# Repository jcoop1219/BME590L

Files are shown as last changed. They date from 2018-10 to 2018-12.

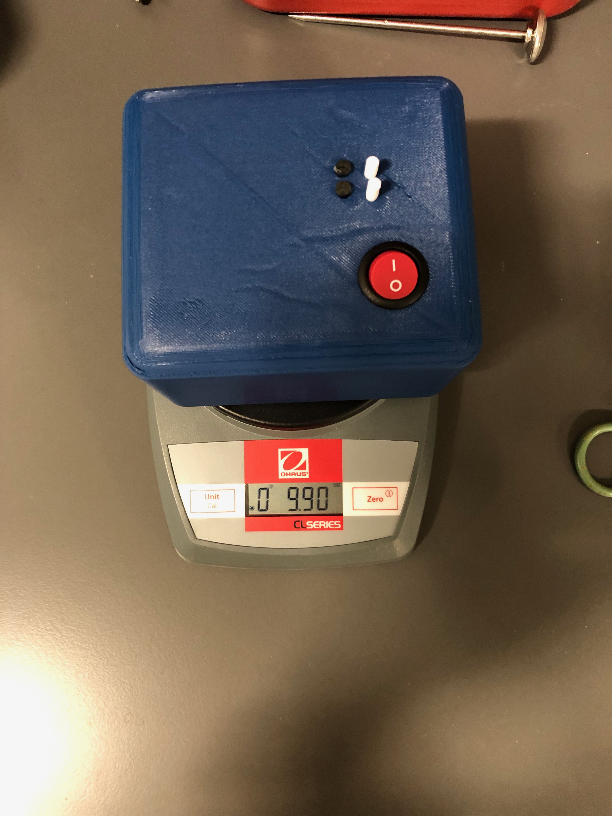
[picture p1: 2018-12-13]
Testing/Total weight.jpg

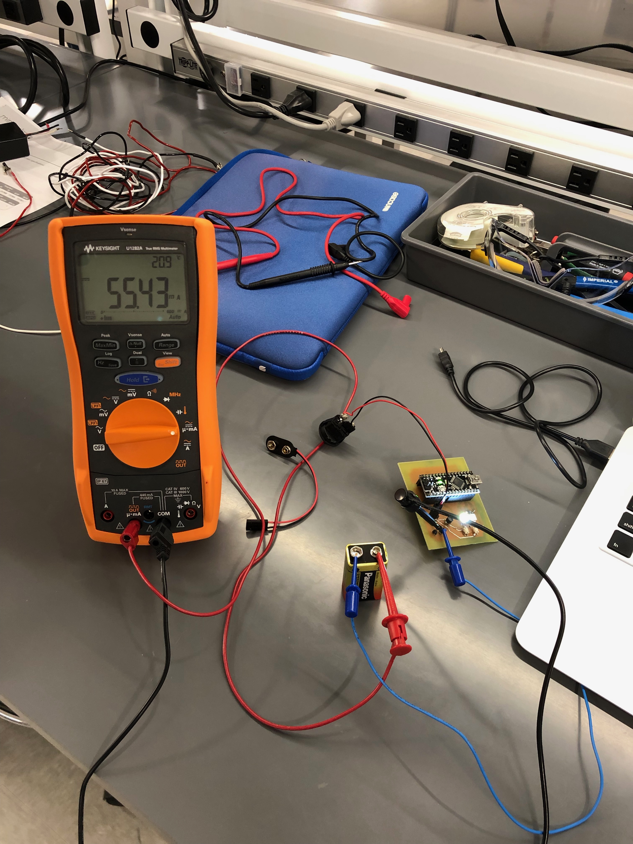
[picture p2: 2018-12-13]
Testing/Current draw.jpg

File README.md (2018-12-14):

# BME590L_Lightbulb - Design Skills Project (Variable Light Intensity)

See Final Working Video on [YouTube](https://youtu.be/NFrjT-VMIhY).

## Usage Guide
1. Turn on device using red I/O switch.
1. Push white button closest to I/O switch to cycle through light modes:
   + `Off`
   + `Brightest`
   + `Intermediate Brightness`
   + `Least Bright`
   + `Flashing @ 2 Hz`
1. Push and hold white button furthest from I/O switch to show the remaining voltage left in the battery on the adjacent LED:
   + `GREEN` = battery high (>8V)
   + `BLUE` = battery medium (7-8V)
   + `RED` = battery low (<7V)

## Battery Replacement
1. Spin flaps on bottom away from center of device.
1. Pull top of case off of bottom of case and disconnect toggle switch Molex connection from board.
1. Remove battery wire Molex connection from board.
1. Remove battery from battery slot.
1. Detach wired cap from battery.
1. Attach wired cap to new battery.
1. Add new battery to battery slot.
1. Re-attach battery wire Molex connection to board.
1. Reconnect toggle switch Molex connection to board.
1. Replace case top over case bottom (note: may need to use tweezers or small object to guide push buttons through case top).
1. Spin flaps on bottom towards center of device.

## Documentation
1. [Bill of Materials](https://github.com/jcoop1219/BME590L_Lightbulb/blob/master/Documentation/Bill%20of%20Materials.xlsx)
1. [Final Device Photos](https://github.com/jcoop1219/BME590L_Lightbulb/tree/master/Documentation/Final%20Device%20Photos)
1. [Testing Videos](https://github.com/jcoop1219/BME590L_Lightbulb/tree/master/Testing/Videos)

## Other Misc Notes:
+ Total weight = 9.9 oz
+ Current draw while on = 55 mA (lasts 7.2 hours on standard 9V battery)
+ Current draw while off = 0 mA (full off ensured by toggle I/O switch)

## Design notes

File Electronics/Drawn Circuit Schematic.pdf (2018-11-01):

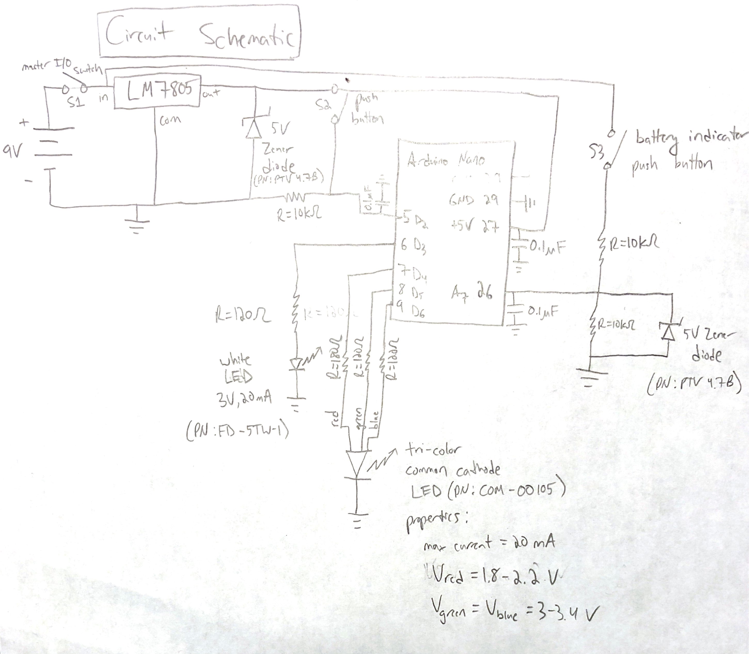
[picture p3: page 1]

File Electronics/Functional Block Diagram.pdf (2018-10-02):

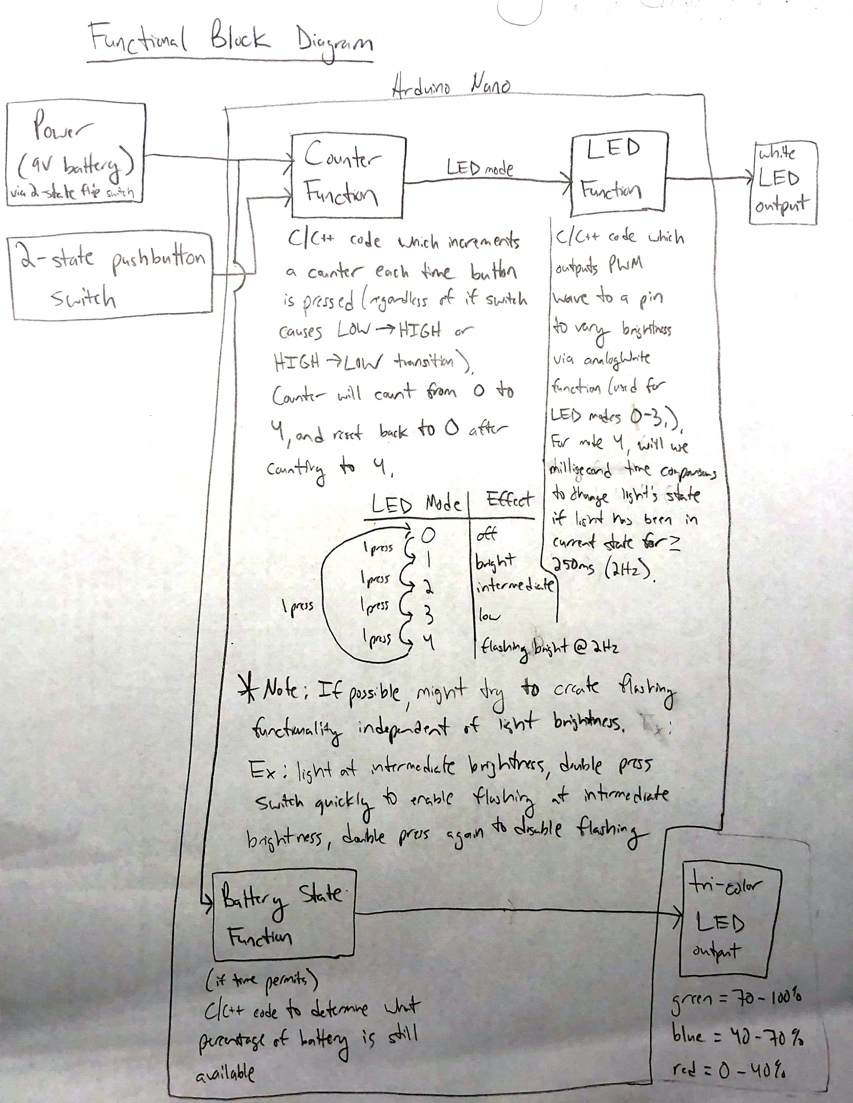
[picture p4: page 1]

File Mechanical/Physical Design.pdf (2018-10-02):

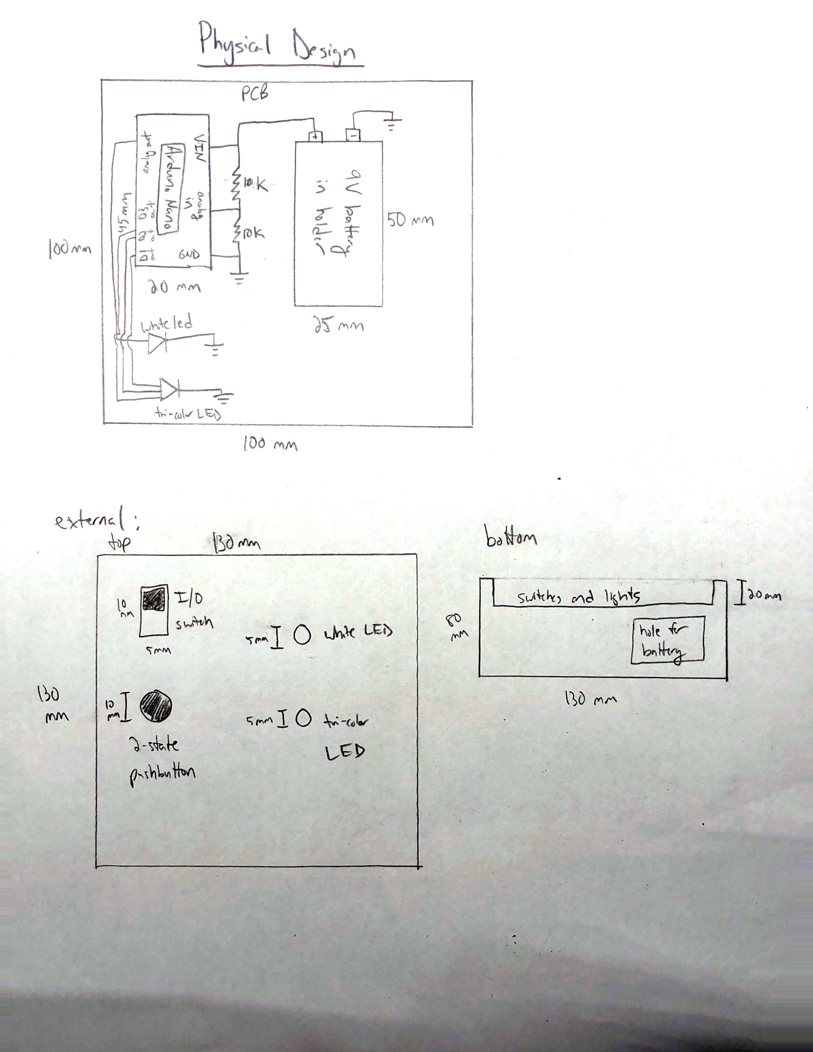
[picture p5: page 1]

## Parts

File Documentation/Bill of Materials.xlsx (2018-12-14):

Item | Cost/Unit | Units | Cost | Source
3D printed items* | $14.24 | 1 | $14.24 | https://www.makeshaper.com/product/blue-pla-2-85-mm-filament/
PCB | $1.00 | 1 | $1.00 | https://www.ebay.com/itm/DIY-Single-PCB-Circuit-Kit-Board-Glass-Fiber-One-Side-Copper-Clad-70x100x1-5mm-/142234873243
Arduino Nano | $22.00 | 1 | $22.00 | https://store.arduino.cc/usa/arduino-nano
9V Battery | $2.38 | 1 | $2.38 | https://www.mouser.com/ProductDetail/Panasonic-Battery/6LF22XWA-B12
Light Pipe LPCR012CTP | $0.53 | 2 | $1.06 | https://www.amazon.com/gp/product/B01N5DIWD6/ref=oh_aui_detailpage_o01_s00?ie=UTF8&psc=1
Push Button SKRPABE010 | $0.36 | 2 | $0.72 | https://www.mouser.com/ProductDetail/ALPS/SKRPABE010?qs=m0BA540hBPe1GpcSf%2FZ5Yw==
SMT Cool White 5050 LED | $0.49 | 1 | $0.49 | https://www.adafruit.com/product/682
SMT RGB 5050 LED | $0.49 | 1 | $0.49 | https://www.adafruit.com/product/619
Toggle Switch RRA22H3FBRNN | $1.28 | 1 | $1.28 | https://www.digikey.com/products/en?mpart=RRA22H3FBRNN&v=85
Voltage Regulator LM7805 TO92 | $1.50 | 1 | $1.50 | https://www.adafruit.com/product/2236
Zener Diode 1n5221 | $0.19 | 1 | $0.19 | https://www.mouser.com/ProductDetail/Vishay-Semiconductors/1N5221B-TAP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
SMT Resistor | $0.11 | 7 | $0.77 | https://www.mouser.com/ProductDetail/Yageo/RC0805JR-070RL?qs=3ldFlDWnkKyEhdaPjQHEFA==
SMT Capacitor | $0.13 | 3 | $0.39 | https://www.digikey.com/product-detail/en/murata-electronics-north-america/GRM2165C1H101JA01D/490-1615-1-ND/587513
Uncountable hours of Matt Brown's time | priceless
TOTAL |  |  | $46.52
*3D printed items calculations:
Piece | Volume (cm^3) | Density of PLA (g/cm^3)** | Cost of PLA ($USD/kg)*** | Total Cost ($USD)
Case Top | 338.68
Case Bottom | 197.16
Plungers (2) | 4.48
Flaps (2) | 0.70
Plunger track | 1.40
TOTAL | 542.42 | 1.25 | $21.00 | $14.24
**https://www.fabbaloo.com/blog/2015/9/27/is-it-filament-weight-or-length
***https://www.makeshaper.com/product/blue-pla-2-85-mm-filament/

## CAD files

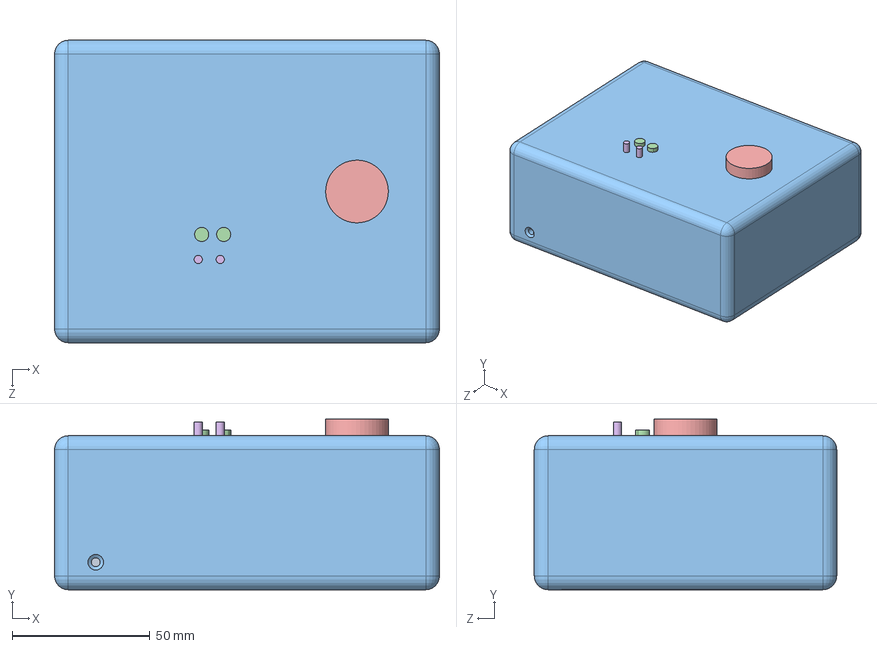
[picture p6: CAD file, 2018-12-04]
Mechanical/Original CAD Design/Case Assembly.SLDASM
140.0 x 62.0 x 110.0 mm
Case Bottom
PCB
Case Top
LCV 116 CTP x 2
Toggle Switch
Push Button Plunger x 2

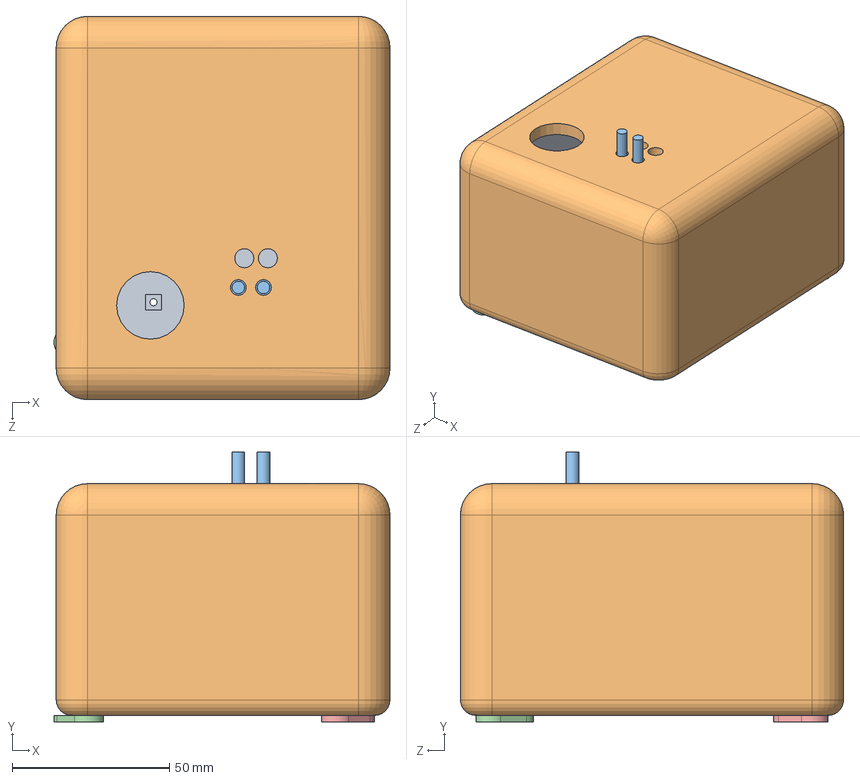
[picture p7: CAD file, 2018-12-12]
Mechanical/New CAD Design/NEW Case Assembly.SLDASM
107.0 x 85.8 x 122.0 mm
NEW Case Bottom
NEW Case Top
NEW Push Button Plunger x 2
Flap Bottom
Flap Bottom 2

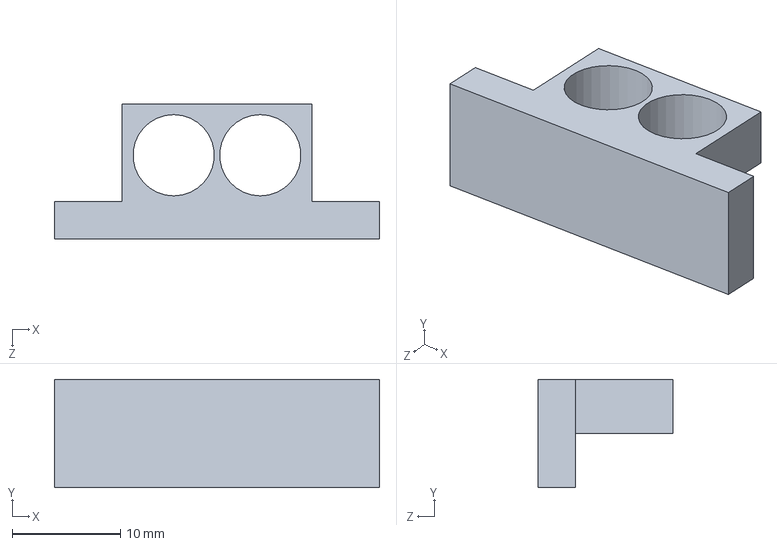
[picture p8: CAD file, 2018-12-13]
Mechanical/New CAD Design/Plunger Track.SLDPRT
30.0 x 10.0 x 12.5 mm

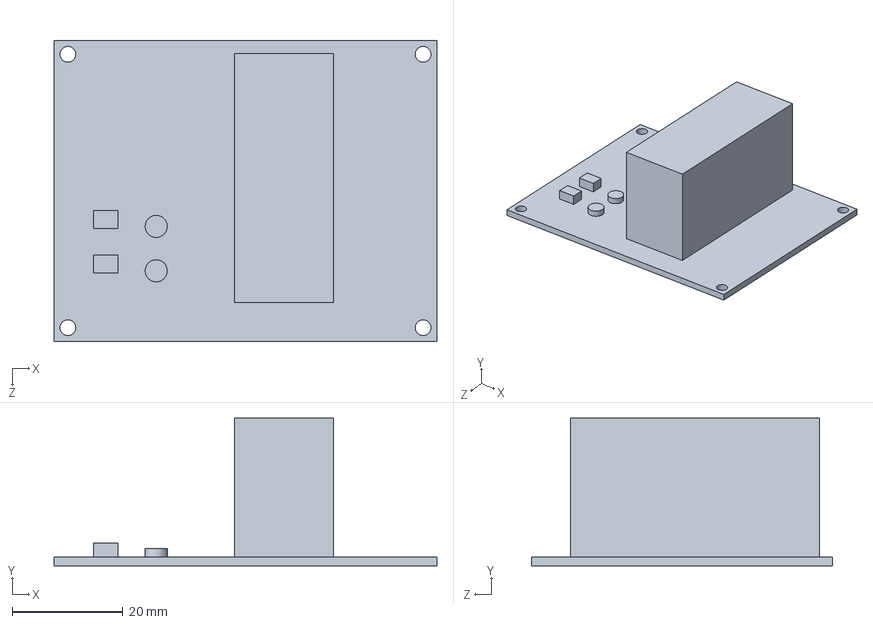
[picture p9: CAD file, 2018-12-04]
Mechanical/Original CAD Design/PCB.SLDPRT
69.0 x 26.6 x 54.3 mm

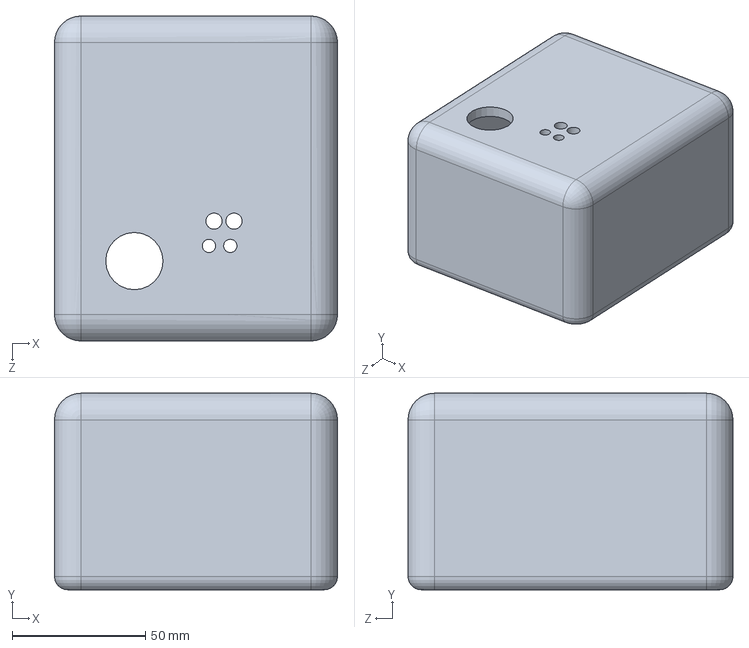
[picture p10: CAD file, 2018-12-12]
Mechanical/New CAD Design/NEW Case Top.SLDPRT
106.3 x 73.8 x 122.0 mm

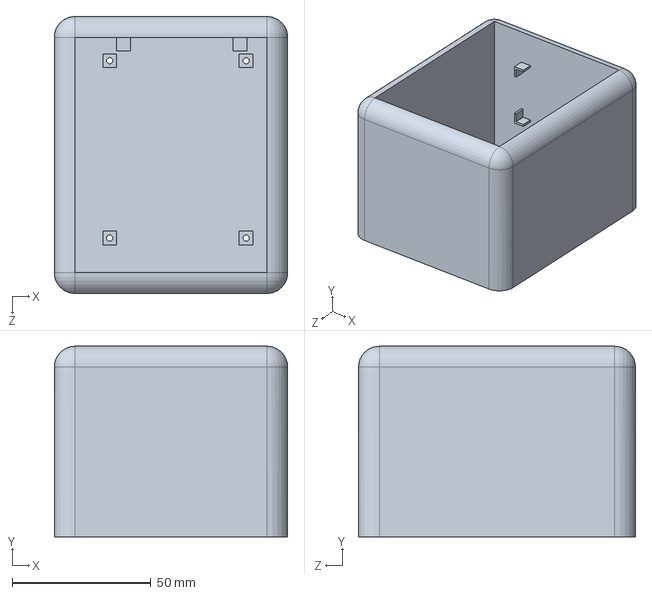
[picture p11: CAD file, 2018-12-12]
Mechanical/New CAD Design/NEW Case Bottom.SLDPRT
84.3 x 68.8 x 100.0 mm

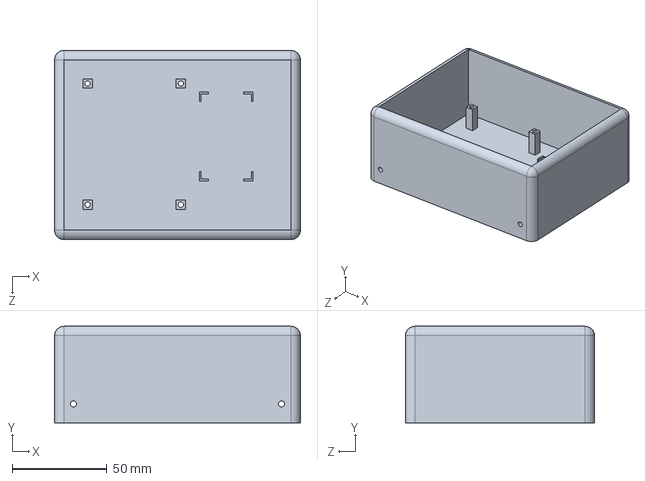
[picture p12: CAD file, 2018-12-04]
Mechanical/Original CAD Design/Case Bottom.SLDPRT
130.0 x 51.0 x 100.0 mm

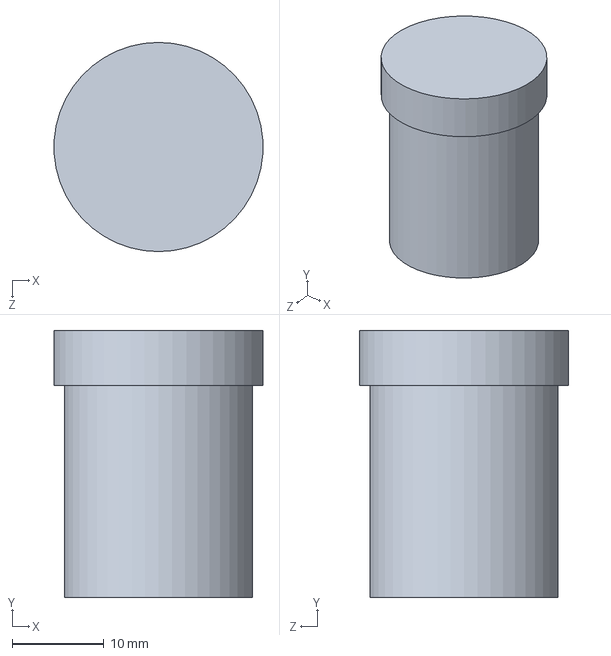
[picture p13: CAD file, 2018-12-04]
Mechanical/Original CAD Design/Toggle Switch.SLDPRT
22.7 x 29.1 x 22.8 mm

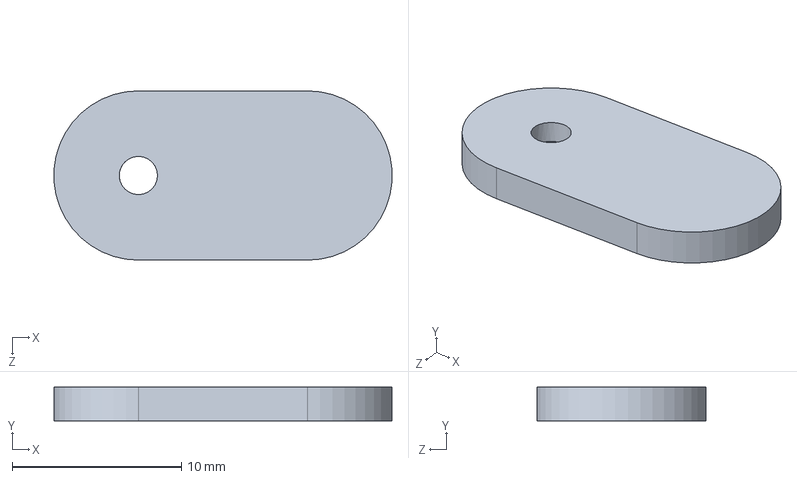
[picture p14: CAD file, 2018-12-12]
Mechanical/New CAD Design/Flap Bottom.SLDPRT
20.0 x 2.00 x 10.0 mm

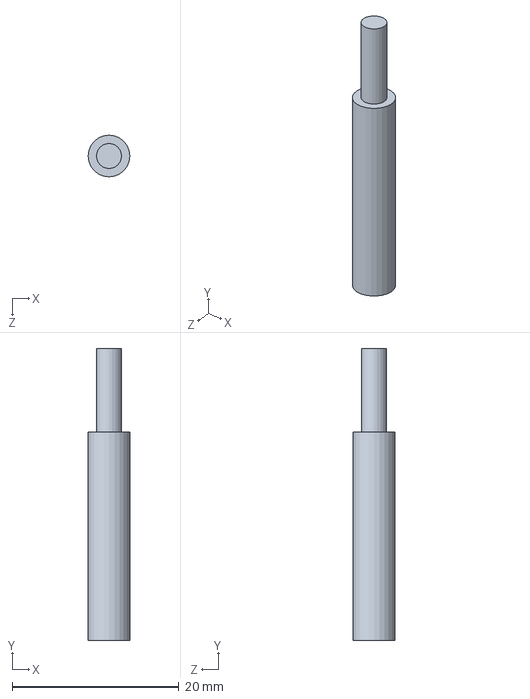
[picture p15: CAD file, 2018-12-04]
Mechanical/Original CAD Design/Push Button Plunger.SLDPRT
5.00 x 35.0 x 5.00 mm

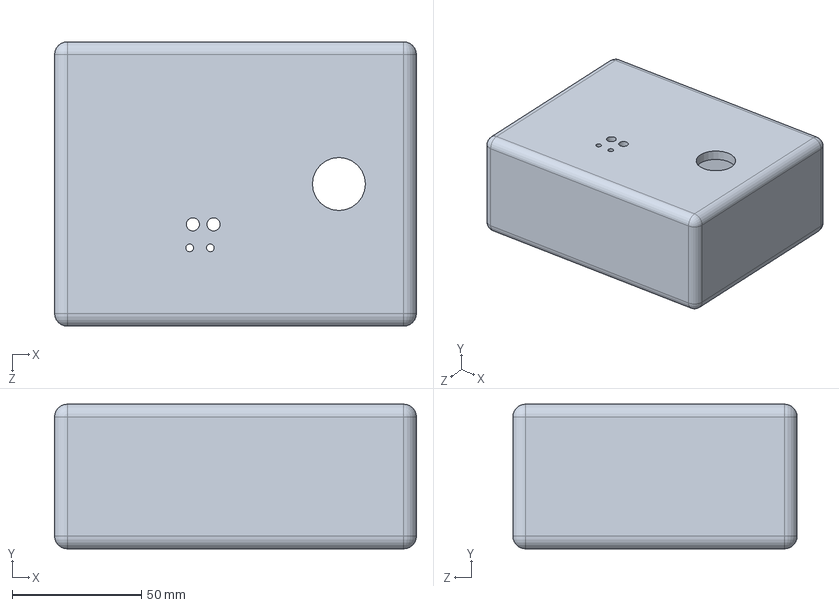
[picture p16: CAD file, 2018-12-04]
Mechanical/Original CAD Design/Case Top.SLDPRT
140.0 x 56.0 x 110.0 mm

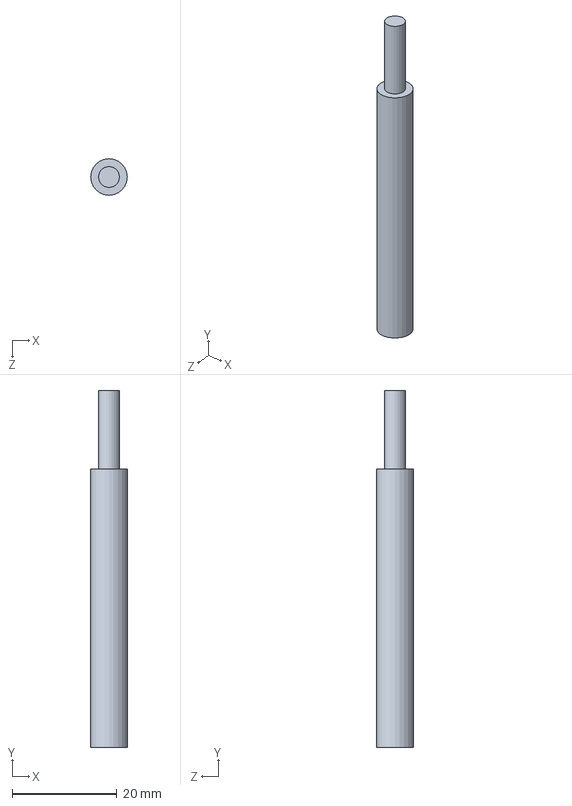
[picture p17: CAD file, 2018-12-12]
Mechanical/New CAD Design/NEW Push Button Plunger.SLDPRT
7.00 x 68.3 x 7.00 mm

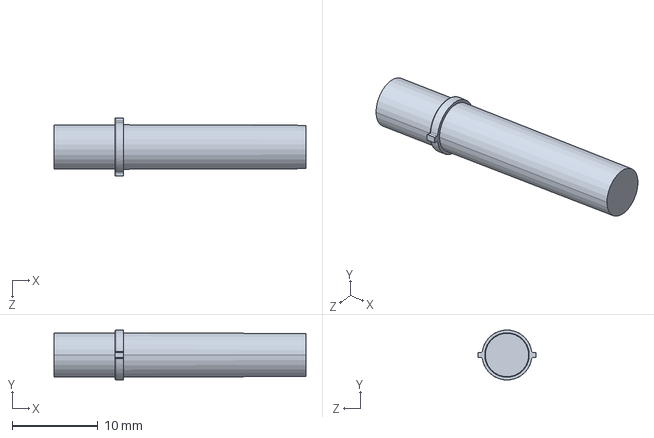
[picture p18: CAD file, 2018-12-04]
Mechanical/Original CAD Design/LCV 116 CTP.SLDPRT
29.5 x 5.84 x 6.76 mm

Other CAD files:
Mechanical/New CAD Design/Flap Bottom 2.SLDPRT
Mechanical/New CAD Design/NEW Push Button Plunger 2.STL
Mechanical/New CAD Design/Flap Bottom 2.STL
Mechanical/New CAD Design/Flap Bottom.STL
Mechanical/New CAD Design/NEW Case Bottom.STL
Mechanical/New CAD Design/NEW Case Top.STL
Mechanical/New CAD Design/NEW Push Button Plunger.STL
Mechanical/New CAD Design/Plunger Track.STL
Mechanical/Original CAD Design/Case Bottom.STL
Mechanical/Original CAD Design/Case Top.STL
Mechanical/Original CAD Design/Push Button Plunger.STL

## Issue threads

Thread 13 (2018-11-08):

Milestone 04 ready for review

jcoop1219, 2018-11-08:
Will also assign to Matt and Brinnae after they accept my invite as collaborators

mlp6, 2018-11-08:
@jcoop1219 you don't seem to like sleep...

mlp6, 2018-11-08:
Let's also add @ericsrichardson

jcoop1219, 2018-11-08:
See minor updates & notes in release v0.2.1

jcoop1219, 2018-11-12:
See newest updates in release v0.2.3

sphaerobolus, 2018-11-12:
I don't think you need ground planes top and bottom. Pick one.

I understand D1, though my opinion is that you don't need it. D1's existence implies you might not trust the voltage regulator. If you don't trust the regulator, get a better one.

I'm not sure I understand D4, nor the use of an analog pin as a switch input.

jcoop1219, 2018-11-12:
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

1. Is there any drawback to having 2 ground planes? I figured having a second ground plane could only help with insulating the circuit from external noise.
2. D1 is really there for the purposes of testing the circuit (like, when building out on breadboard). Using it to make sure I'm not discharging any static electricity >5V from my clothing to the Arduino. I'll remove D1 from the PCB.
3. I'm using this analog input as a battery voltage tester (to see how much juice is left in the battery). Ideally what's going into this input should never be above 4.5V (9V battery divided by 2 via voltage divider). D4 ensures this voltage won't go above 5.1V and I won't fry the Arduino.

jcoop1219, 2018-11-12:
@sphaerobolus please see my comment above in response to your questions

sphaerobolus, 2018-11-12:
In your case I think the added plane will merely be redundant. In some cases it can be problematic. It's not doing you much good. The positive effects do not add linearly.

Ah, now I understand the analog input. In that case, I'm on board. Carry on.

jcoop1219, 2018-11-12:
Thanks! I'll go ahead and remove the bottom layer ground plane, as well as remove D1 per the discussion above.

Closed 2018-11-12.

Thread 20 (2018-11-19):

Add screw holes to box design

jcoop1219, 2018-11-19:

jcoop1219, 2018-11-27:
- Most common screw in lab: 4-40
- Wood screws fine to use as long as not often screwing/unscrewing; tap into material
- Machine screw need threaded entity to go into or a nut

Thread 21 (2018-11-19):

Milestone 05 ready for review

jcoop1219, 2018-11-19:
See latest release notes for [v0.3.0](https://github.com/jcoop1219/BME590L_Lightbulb/releases/tag/v0.3.0)

mlp6, 2018-11-26:
@jcoop1219 how do your top and bottom secure to one another?  There also seem to be a lack of internal mounting points for the board(s), battery, etc.

mlp6, 2018-11-26:
Noticed you still have some open Issues that will address some of these things.

jcoop1219, 2018-12-03:
These issues (attachment of top to bottom, battery attachment, PCB) all addressed newest release [v0.3.1](https://github.com/jcoop1219/BME590L_Lightbulb/releases/tag/v0.3.1)

mlp6, 2018-12-03:
Impressive!

jcoop1219, 2018-12-03:
Thanks! Do you think I'm good to proceed with printing this?

mlp6, 2018-12-04:
I think so... but there is no substitute for evaluating it in tangible form (for me).

Closed 2018-12-08.

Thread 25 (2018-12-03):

Look into springs for button plungers

jcoop1219, 2018-12-03:

jcoop1219, 2018-12-11:
Not going to pursue this. Will just give very small (2-3 mm) clearance where button might wiggle a little up and down but should be held in box by mechanical design.

Closed 2018-12-11.

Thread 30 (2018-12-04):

Battery testing circuit working erratically

jcoop1219, 2018-12-04:
When pushing button to test circuit, correct LED lights up (shows red, green, or blue based on the voltage left in the battery). After letting button go, red LED lights up briefly. It seems that the analog in pin is seeing some stray voltage even after that part of the circuit is switched off. I would guess that there's some sort of stray capacitance which is discharging and causing this behavior.

I removed the nearby bypass capacitor, but that didn't seem to do the trick.

Is it possible that one of the other capacitors (in completely different parts of circuit) are causing this stray capacitance? Or could it be the solder pattern on the board?

Will try to solve this with a software-side solution...

jcoop1219, 2018-12-08:
Fixed this by upping the lower threshold which considers the battery to be "dead"

Closed 2018-12-08.

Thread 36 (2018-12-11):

Mechanical redesign

jcoop1219, 2018-12-11:
1. Make all holes wider by 1-2mm
2. Give 1-2mm clearance all around
3. Shorten stumps for PCB placement to 7-10mm
4. Battery above PCB
5. Toggle switch moved directly above area where it plugs into on board
6. Light pipes either chained or chained and cut
7. Re-model plungers
8. More rounded edges

Closed 2018-12-12.

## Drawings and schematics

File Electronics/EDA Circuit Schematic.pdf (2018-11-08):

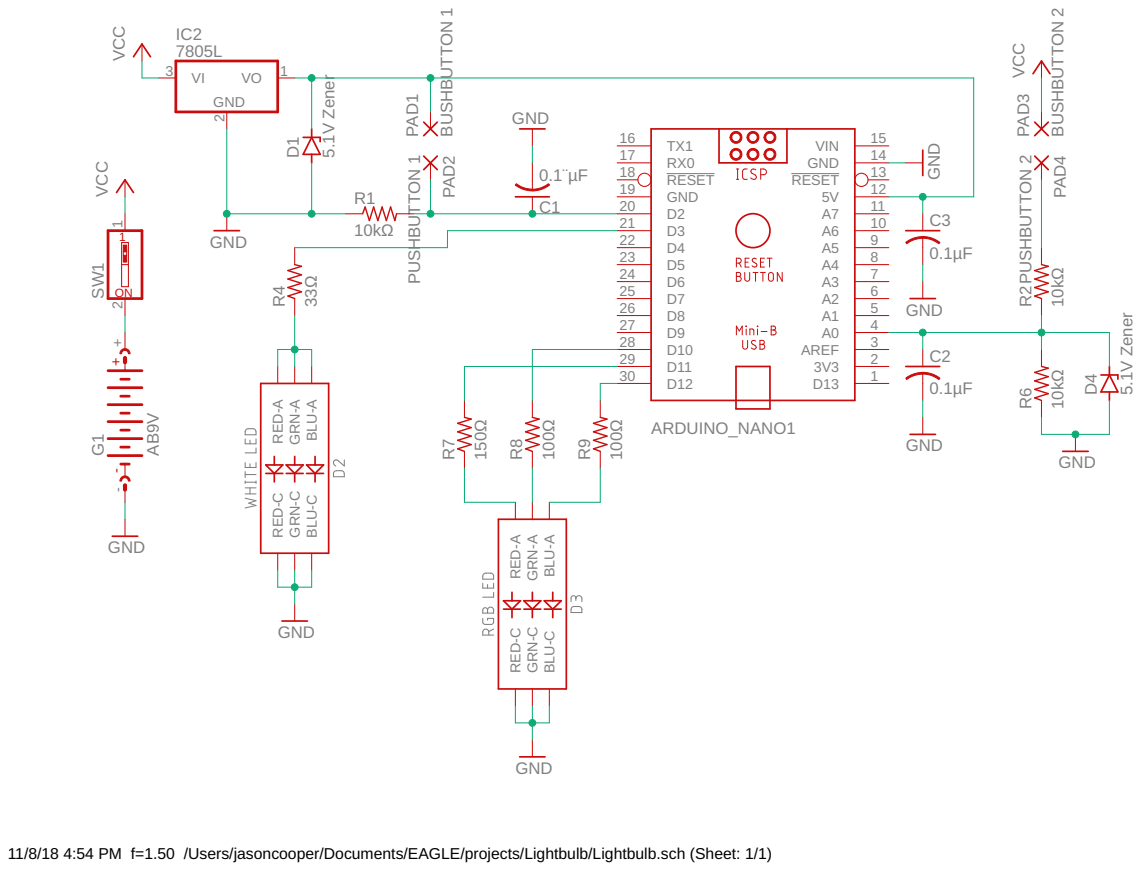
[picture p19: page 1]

GND

GND D2 D3 D4 D7 D8 | 5V | 14 VIN

11/8/18 4:54 PM f=1.50 /Users/jasoncooper/Documents/EAGLE/projects/Lightbulb/Lightbulb.sch (Sheet: 1/1)

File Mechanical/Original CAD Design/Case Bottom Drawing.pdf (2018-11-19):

108.000
106.000

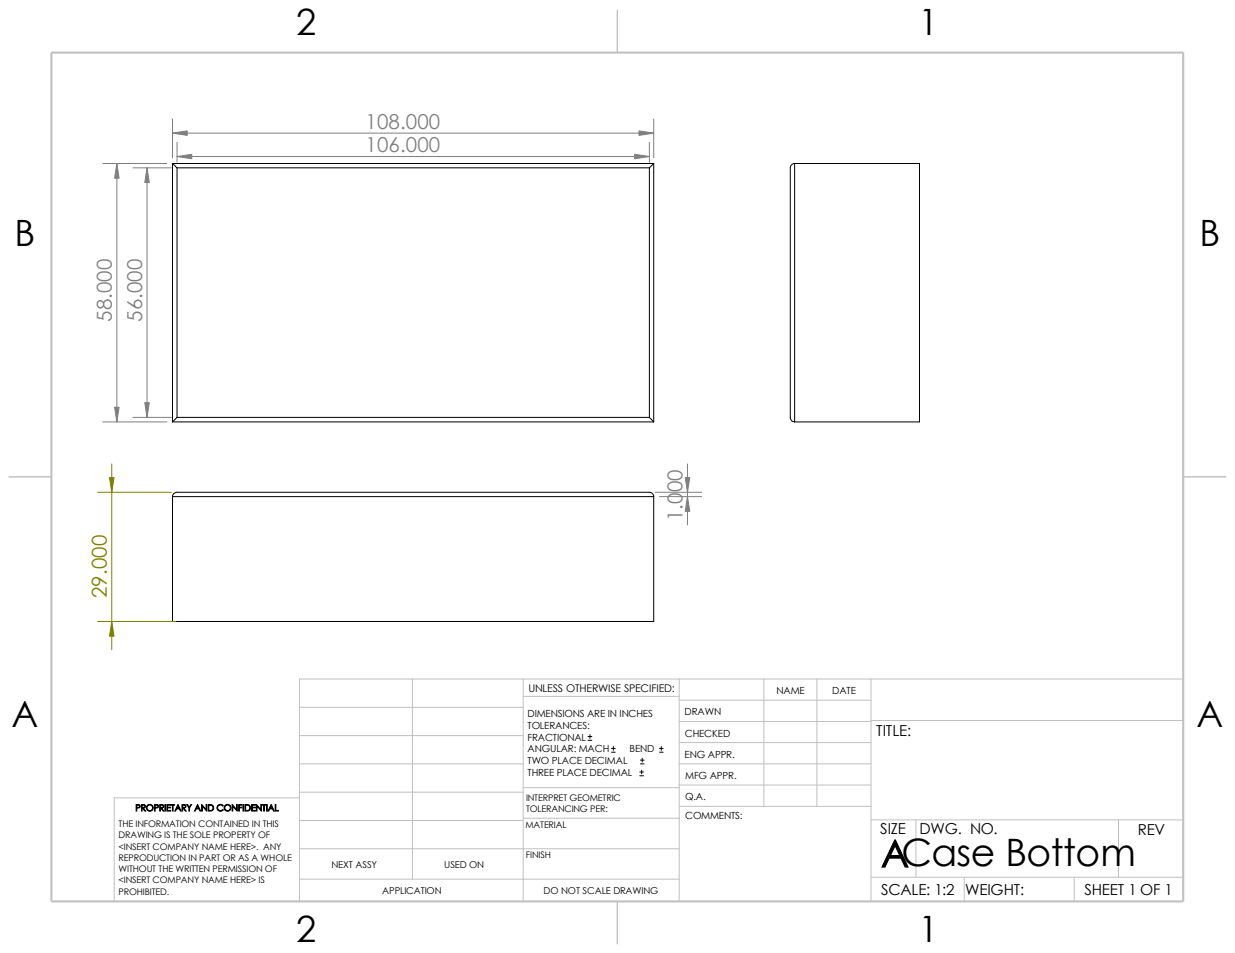
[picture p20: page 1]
COMMENTS:; INTERPRET GEOMETRIC; PROPRIETARY AND CONFIDENTIAL; TOLERANCING PER:

UNLESS OTHERWISE SPECIFIED: | | NAME | DATE

DIMENSIONS ARE IN INCHES TOLERANCES: FRACTIONAL ANGULAR: MACH BEND TWO PLACE DECIMAL THREE PLACE DECIMAL | DRAWN

CHECKED | | | TITLE:

ENG APPR.
MFG APPR.

THE INFORMATION CONTAINED IN THIS
DRAWING IS THE SOLE PROPERTY OF
<INSERT COMPANY NAME HERE>. ANY
REPRODUCTION IN PART OR AS A WHOLE
WITHOUT THE WRITTEN PERMISSION OF
<INSERT COMPANY NAME HERE> IS
PROHIBITED.

MATERIAL | | SIZE A Case Bottom | DWG. NO. | REV

NEXT ASSY | USED ON | FINISH

APPLICATION | DO NOT SCALE DRAWING | | SCALE: 1:2 | WEIGHT: | SHEET 1 OF 1

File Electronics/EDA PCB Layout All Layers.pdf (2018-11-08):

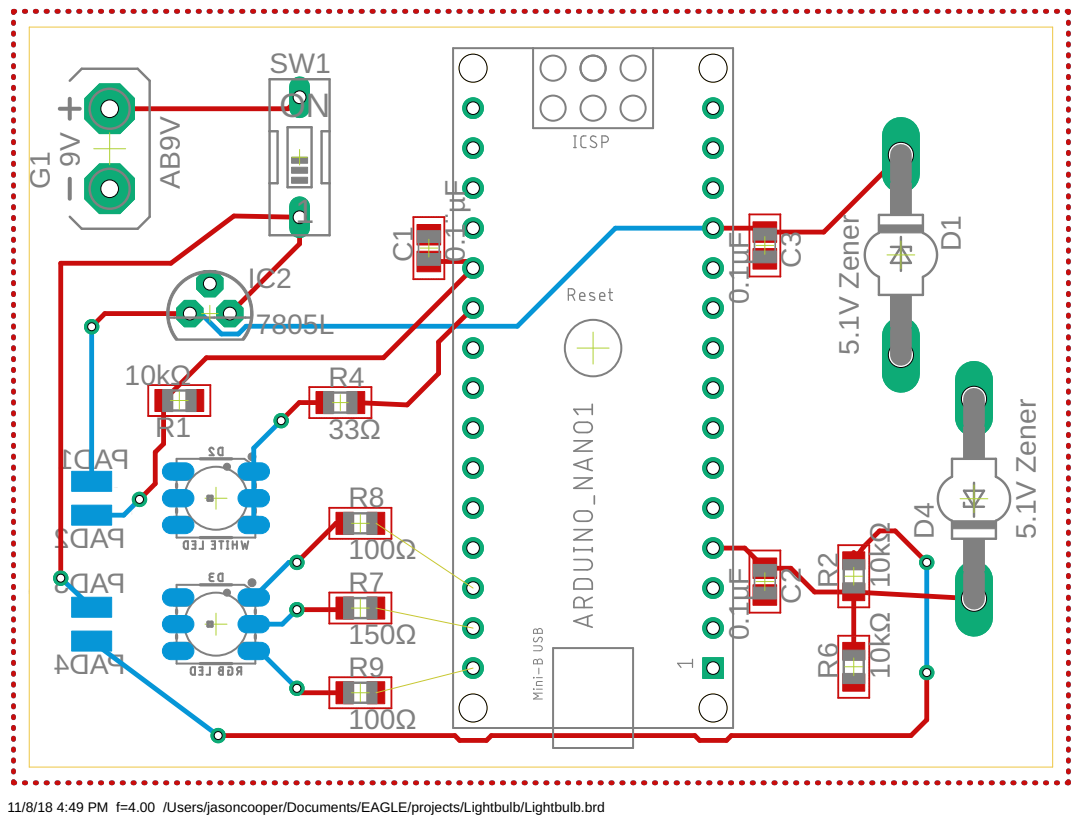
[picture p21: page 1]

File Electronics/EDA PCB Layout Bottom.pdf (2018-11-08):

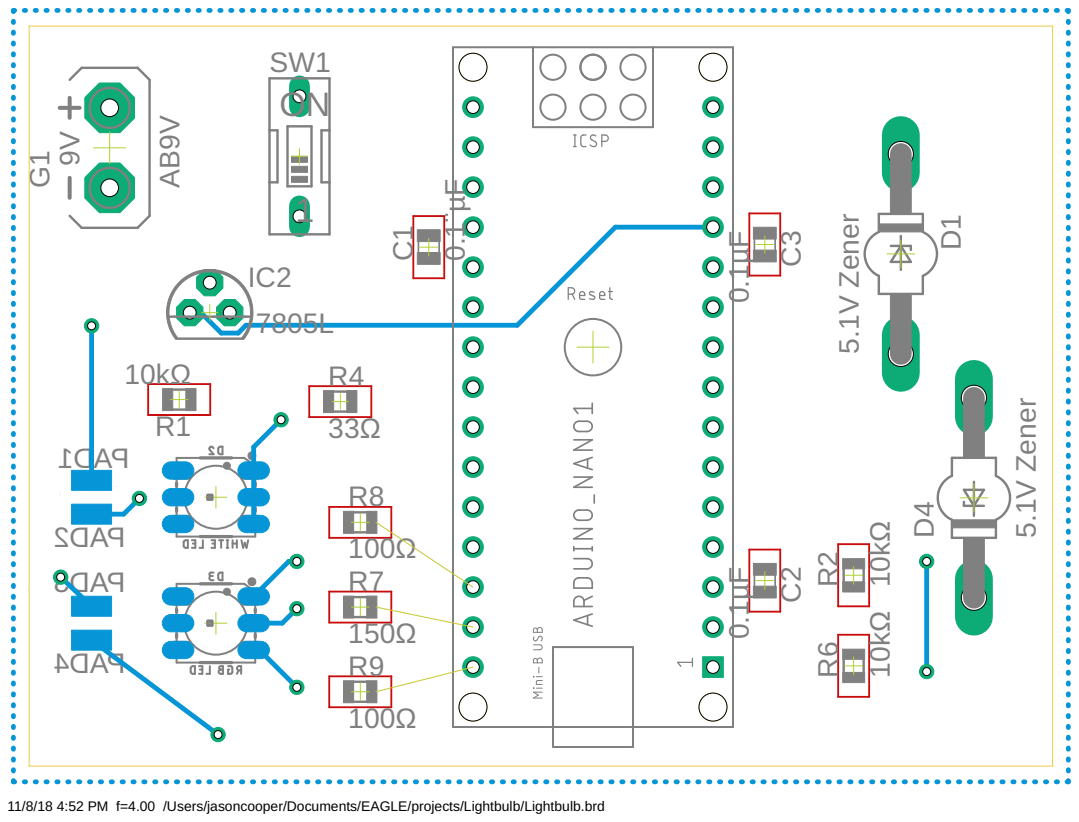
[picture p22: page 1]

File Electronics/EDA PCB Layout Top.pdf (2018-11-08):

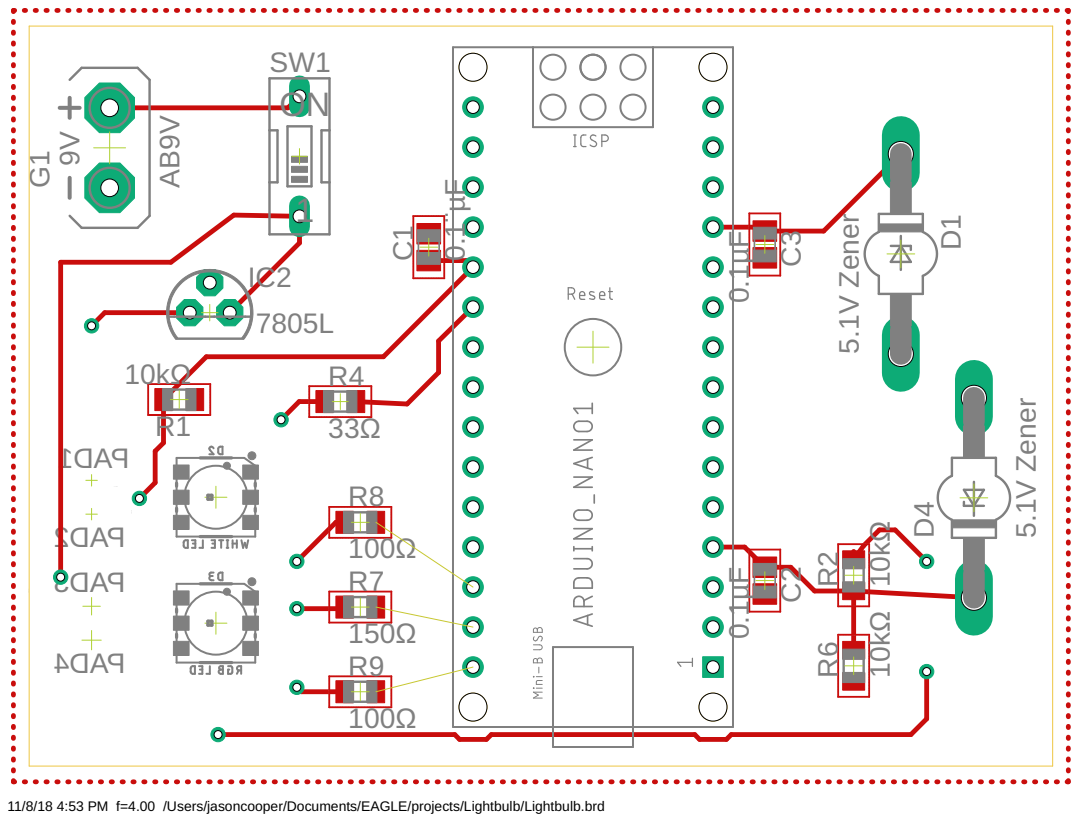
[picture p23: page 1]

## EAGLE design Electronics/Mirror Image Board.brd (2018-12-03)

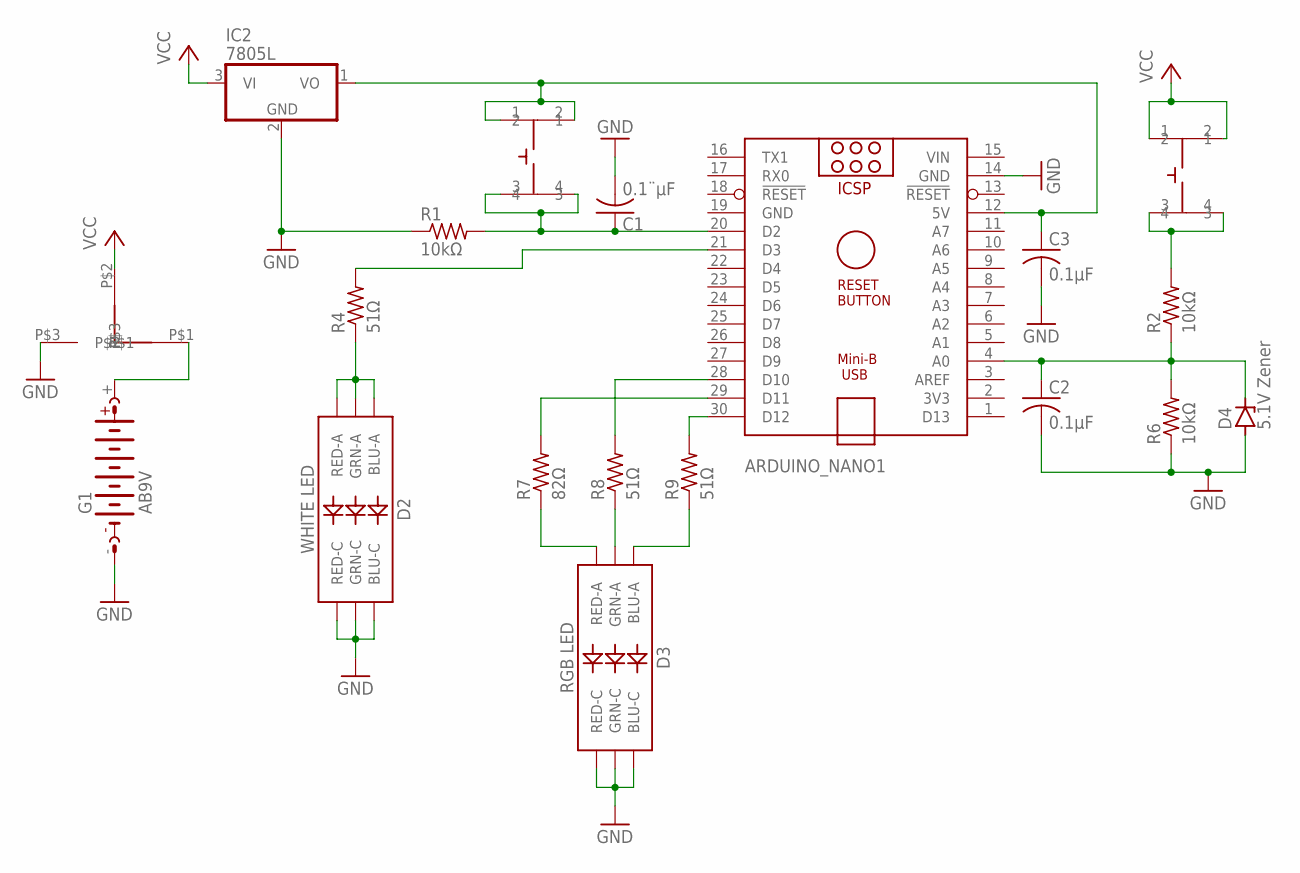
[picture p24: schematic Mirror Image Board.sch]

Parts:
ARDUINO_NANO1: ARDUINO_NANO
C1: 0.1¨µF; C0805
C2, C3: 0.1µF; C0805
D2: WHITE LED; LED-TRICOLOR-5050
D3: RGB LED; LED-TRICOLOR-5050
D4: 5.1V Zener; SOD64Z12
G1: AB9V
IC2: 7805L; TO92
R1, R2, R6: 10kΩ; R0805
R4, R8, R9: 51Ω; R0805
R7: 82Ω; R0805
U$1, U$2: SKRPABE010
U$3: DIPSWITCH

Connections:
GND: ARDUINO_NANO1.14 (GND), ARDUINO_NANO1.19 (GND), C1.2, C2.2, C3.2, D2.4 (BLU-C), D2.5 (RED-C), D2.6 (GRN-C), D3.4 (BLU-C), D3.5 (RED-C), D3.6 (GRN-C), D4.A, G1.-, IC2.2 (GND), R1.1, R6.1, U$3.P$3
unnamed: G1.+, U$3.P$1
unnamed: ARDUINO_NANO1.30 (D12), R9.2
unnamed: ARDUINO_NANO1.20 (D2), C1.1, R1.2, U$1.3, U$1.4
unnamed: ARDUINO_NANO1.12 (5V), C3.1, IC2.1 (VO), U$1.1, U$1.2
unnamed: ARDUINO_NANO1.4 (A0), C2.1, D4.C, R2.1, R6.2
unnamed: R2.2, U$2.3, U$2.4
unnamed: ARDUINO_NANO1.21 (D3), R4.2
unnamed: ARDUINO_NANO1.29 (D11), R7.2
unnamed: D3.2 (RED-A), R7.1
unnamed: D3.1 (GRN-A), R8.1
unnamed: D3.3 (BLU-A), R9.1
unnamed: ARDUINO_NANO1.28 (D10), R8.2
unnamed: D2.1 (GRN-A), D2.2 (RED-A), D2.3 (BLU-A), R4.1
VCC: IC2.3 (VI), U$2.1, U$2.2, U$3.P$2
VIN: ARDUINO_NANO1.15 (VIN)

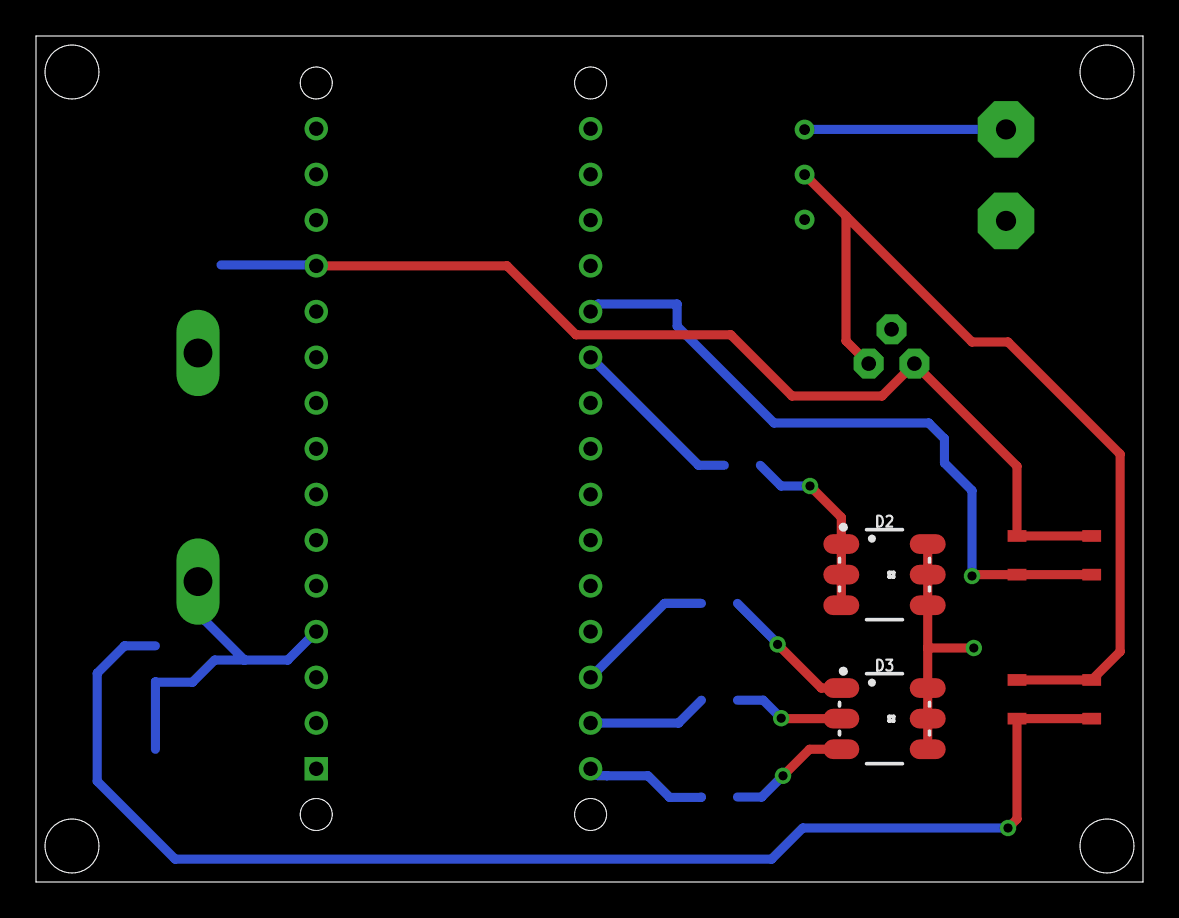
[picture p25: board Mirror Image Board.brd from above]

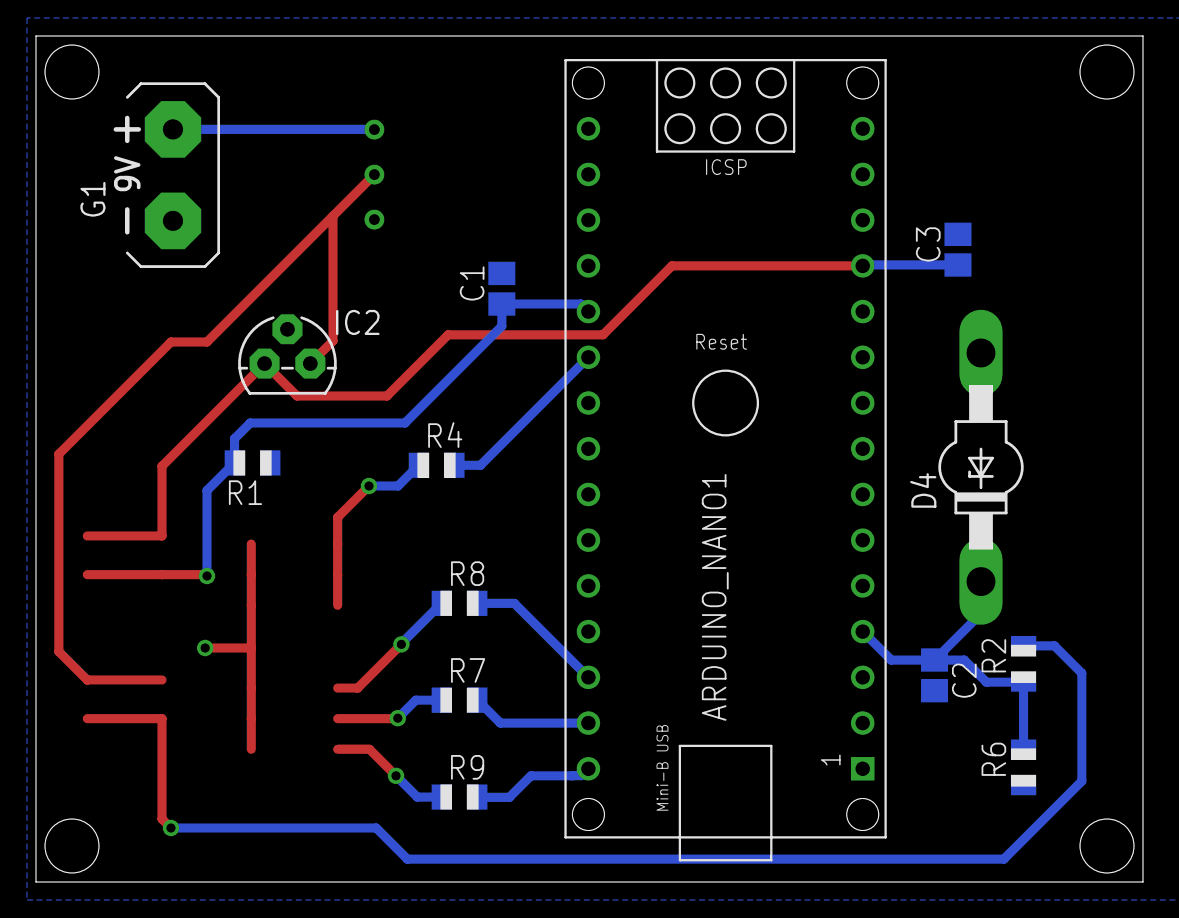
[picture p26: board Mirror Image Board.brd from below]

Board: 2 copper layers, 61.5 x 47.0 mm, 19 parts (15 on the bottom side), 15 nets.

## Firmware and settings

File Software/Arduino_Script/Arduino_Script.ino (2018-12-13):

// parameters
const int flashRateHz = 2;  //rate of blinking for flash mode
const int pwmMax = 255;  //max threshold for PWM signal
const int debounceDelayMs = 100;  //debounce on main button
const float deadBatteryVoltage = 5.4;  //threshold for dead battery
const float lowBatteryVoltage = 7;  //threshold for low voltage on battery
const float medBatteryVoltage = 8;  //threshold for med voltage on battery
const float conversionFactor = 100.8; //used to convert battery voltage thresholds to 0-1023 digital range read-in via voltage divider circuit

// I/O pins
const int buttonIn = 2;  //main button digital in
const int whiteLEDout = 3;  //main LED digital out
const int greenLEDout = 10;  //battery tester LED digital out
const int redLEDout = 11;  //battery tester LED digital out
const int blueLEDout = 12;  //battery tester LED digital out
const int batteryVoltageIn = 0;  //battery tester analog in

// global variables
int mode = 0;  //flashing mode
bool buttonPushed = false;
int pwmOut = 0; //0-255 PWM signal
unsigned long lastDebounceTime = 0;
int batteryVoltage = 0;
unsigned long lastFlashTime = 0;
bool flashMode = LOW;


void setup() {
  pinMode(whiteLEDout,OUTPUT);
  pinMode(redLEDout,OUTPUT);
  pinMode(greenLEDout,OUTPUT);
  pinMode(blueLEDout,OUTPUT);
  attachInterrupt(digitalPinToInterrupt(buttonIn),detectButtonPress,RISING);
  
}

void loop() {
  setMode();  //sets flashing mode
  outputLight();  //outputs light based on flashing mode
  checkBattery();  //checks battery voltage
  outputBatteryIndicator();  //outputs to RBG LED based on battery voltage remaining
}

void detectButtonPress() {
  if ((millis() - lastDebounceTime) > debounceDelayMs) {
    buttonPushed = true;
    lastDebounceTime = millis();
  }
}

void setMode() {
  if (buttonPushed) {
    if (mode == 4) {
      mode = 0;
    }
    else {
      ++mode;
    }
    buttonPushed = false;
  }
}

void outputLight() {
  switch (mode) {
    case 0:  //off
      pwmOut = 0;
      shineLED();
      break;
    case 1:  //full brightness
      pwmOut = pwmMax;
      shineLED();
      break;
    case 2:  //medium brightness
      pwmOut = int(pwmMax/2);
      shineLED();
      break;
    case 3:  //low brightness
      pwmOut = int(pwmMax/4);
      shineLED();
      break;
    case 4:  //flashing
      flashLED();
      break;
  }
}

void shineLED() {
  analogWrite(whiteLEDout,pwmOut);
}

void flashLED() {
  if ((millis() - lastFlashTime) >= (500/flashRateHz)) {
    flashMode = !flashMode;
    digitalWrite(whiteLEDout,flashMode);
    lastFlashTime = millis();
  }
}

void checkBattery() {
  batteryVoltage = analogRead(batteryVoltageIn);
}

void outputBatteryIndicator() {
  if (batteryVoltage < (deadBatteryVoltage*conversionFactor)) {  //battery votlage < 5.4V is dead
    digitalWrite(redLEDout,LOW);
    digitalWrite(blueLEDout,LOW);
    digitalWrite(greenLEDout,LOW);
  }
  else if (batteryVoltage < (lowBatteryVoltage*conversionFactor)) {  //battery voltage < 7V is low
    digitalWrite(redLEDout,HIGH);
    digitalWrite(blueLEDout,LOW);
    digitalWrite(greenLEDout,LOW);
  }
  else if (batteryVoltage < (medBatteryVoltage*conversionFactor)) {  //battery voltage < 8V is medium
    digitalWrite(redLEDout,LOW);
    digitalWrite(blueLEDout,HIGH);
    digitalWrite(greenLEDout,LOW);
  }
  else {  //battery voltage >=8V is high
    digitalWrite(redLEDout,LOW);
    digitalWrite(blueLEDout,LOW);
    digitalWrite(greenLEDout,HIGH);
  }
}

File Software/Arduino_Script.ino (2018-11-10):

// parameters
const int flashRateHz = 2;
const int pwmMax = 255;
const int debounceDelayMs = 50;
const int lowBatteryVoltage = 7.5;
const int medBatteryVoltage = 8.5;

// I/O pins
const int buttonIn = 20;
const int whiteLEDout = 21;
const int greenLEDout = 28;
const int redLEDout = 29;
const int blueLEDout = 30;
const int batteryVoltageIn = 4;

// global variables
int mode = 0;
bool buttonPushed = true;
int pwmOut = 0; //0-255
bool prevButtonState = true;
int lastDebounceTime = 0;
int batteryVoltage = 0;


void setup() {
  attachInterrupt(digitalPinToInterrupt(buttonIn),detectButtonPress,CHANGE);
}

void loop() {
  setMode();
  outputLight();
  checkBattery();
  outputBatteryIndicator();
}

void detectButtonPress() {
  buttonPushed = !buttonPushed;
}

void setMode() {
  if (buttonPushed != prevButtonState) {
    lastDebounceTime = millis();
  }
  if ((millis() - lastDebounceTime) > debounceDelayMs) {
    if (mode = 4) {
      mode = 0;
    }
    else {
      ++mode;
    }
  }
  prevButtonState = buttonPushed;
}

void outputLight() {
  switch (mode) {
    case 0:
      pwmOut = 0;
      shineLED();
      break;
    case 1:
      pwmOut = pwmMax;
      shineLED();
      break;
    case 2:
      pwmOut = int(pwmMax/2);
      shineLED();
      break;
    case 3:
      pwmOut = int(pwmMax/4);
      shineLED();
      break;
    case 4:
      flashLED();
      break;
  }
}

void shineLED() {
  analogWrite(whiteLEDout,pwmOut);
}

void flashLED() {
  digitalWrite(whiteLEDout,HIGH);
  delay(500/flashRateHz);
  digitalWrite(whiteLEDout,LOW);
  delay(500/flashRateHz);
}

void checkBattery() {
  batteryVoltage = analogRead(batteryVoltageIn);
}

void outputBatteryIndicator() {
  if (batteryVoltage < 100) {
    digitalWrite(redLEDout,LOW);
    digitalWrite(blueLEDout,LOW);
    digitalWrite(greenLEDout,LOW);
  }
  else if (batteryVoltage < (102.4*lowBatteryVoltage)) {
    digitalWrite(redLEDout,HIGH);
    digitalWrite(blueLEDout,LOW);
    digitalWrite(greenLEDout,LOW);
  }
  else if (batteryVoltage < (102.4*medBatteryVoltage)) {
    digitalWrite(redLEDout,LOW);
    digitalWrite(blueLEDout,HIGH);
    digitalWrite(greenLEDout,LOW);
  }
  else {
    digitalWrite(redLEDout,LOW);
    digitalWrite(blueLEDout,LOW);
    digitalWrite(greenLEDout,HIGH);
  }
}

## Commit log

2018-11-01 Full circuit schematic and Arduino software flowchart
2018-11-08 Initial completion of EDA schematic, EDA circuit board, and Arduino code
    [Lightbulb.brd, Lightbulb.sch]
2018-11-08 Actually committing Arduino script this time...
2018-11-08 Moving switches and LEDs to bottom side of board
    [Lightbulb.brd, Lightbulb.sch]
2018-11-11 Updated board layout to put master switch on back and added connections for RGB LED
    [Lightbulb.brd]
2018-11-13 Correcting pad placement and connections on PCB
    [Lightbulb.brd, Lightbulb.sch]
2018-11-13 Finalizing Arduino script
2018-11-19 Moving small components further from MCU on board, tweaking ADC part of code for battery tester
    [Lightbulb.brd]
2018-11-19 Updating board with custom-made footprints for push buttons
    [Lightbulb.brd, Lightbulb.sch]
2018-11-19 correct spacing on pushbuttons
    [Lightbulb.brd]
2018-11-19 case mechanical drawings and 3D renderings
    [Case Assembly.SLDASM, Case Bottom.SLDDRW, Case Bottom.SLDPRT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]
2018-11-27 Larger trace widths and new footprint for dip switch
    [Lightbulb.brd, Lightbulb.sch]
2018-11-30 Correct trace widths this time (Matt Brown approved)
    [Lightbulb.brd, Lightbulb.sch]
2018-12-03 Major updates to mechanical design based on etched PCB
    [Case Assembly.SLDASM, Case Bottom.SLDDRW, Case Bottom.SLDPRT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]
2018-12-03 Integrated push button plunger and initial screw hole
    [Case Assembly.SLDASM, Case Bottom.SLDPRT, Case Top.SLDPRT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]
2018-12-03 Added all screw holes
    [Case Assembly.SLDASM, Case Bottom.SLDPRT, Case Top.SLDPRT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]
2018-12-03 updating a few resistor values for diodes to prevent draw of too much current from Arduino
    [Lightbulb.brd, Lightbulb.sch]
2018-12-03 Changing resistor values and uploading mirror image of board
    [Mirror Image Board.brd, Mirror Image Board.sch]
2018-12-04 Mechanical updates to incorporate new screw holes
    [Case Assembly.SLDASM, Case Bottom.SLDPRT, Case Bottom.STL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]
2018-12-04 Adding testing data showing electronics working on PCB
2018-12-08 Fine tuning battery tester voltage thresholds
2018-12-08 Battery testing circuit video
2018-12-12 Mechanical redesign files
    [NEW Case Assembly.SLDASM, NEW Case Bottom.SLDPRT, NEW Case Bottom.STL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]
2018-12-12 Added mechanical flaps to hold box together
    [Flap Bottom 2.SLDPRT, Flap Bottom 2.STL, Flap Bottom.SLDPRT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]
2018-12-13 Adding 9V battery spec sheet
2018-12-13 Adding pic showing circuit's current draw at full brightness
2018-12-13 Documentation updates and adding bill of materials
    [Bill of Materials.xlsx]
2018-12-13 Adding plunger track
    [Plunger Track.SLDPRT, Plunger Track.STL]
2018-12-13 Adding video showing entire thing working in case
2018-12-14 Updated Bill of Materials
    [Bill of Materials.xlsx]
2018-12-14 Mechanical design folder re-org
    [Case Assembly.SLDASM, Case Bottom.SLDPRT, Case Bottom.STL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]
2018-12-14 Rename documentation folder
    [Bill of Materials.xlsx]

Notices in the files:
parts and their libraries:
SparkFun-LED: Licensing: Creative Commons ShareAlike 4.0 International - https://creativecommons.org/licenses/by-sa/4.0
